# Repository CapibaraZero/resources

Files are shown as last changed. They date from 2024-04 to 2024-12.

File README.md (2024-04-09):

# CapibaraZero Resources

Here lives the resources needed for building a complete CapibaraZero

## Structure

- PCB/ Gerber and EasyEDA JSON files
- electrical_diagram/ Electrical diagram of CapibaraZero in PNG and EasyEDA JSON
- STL/ Box of capibaraZero

### Supported platforms

- CapibaraZero ESP32-S3-DevKitC-1
- CapibaraZero Arduino Nano ESP32

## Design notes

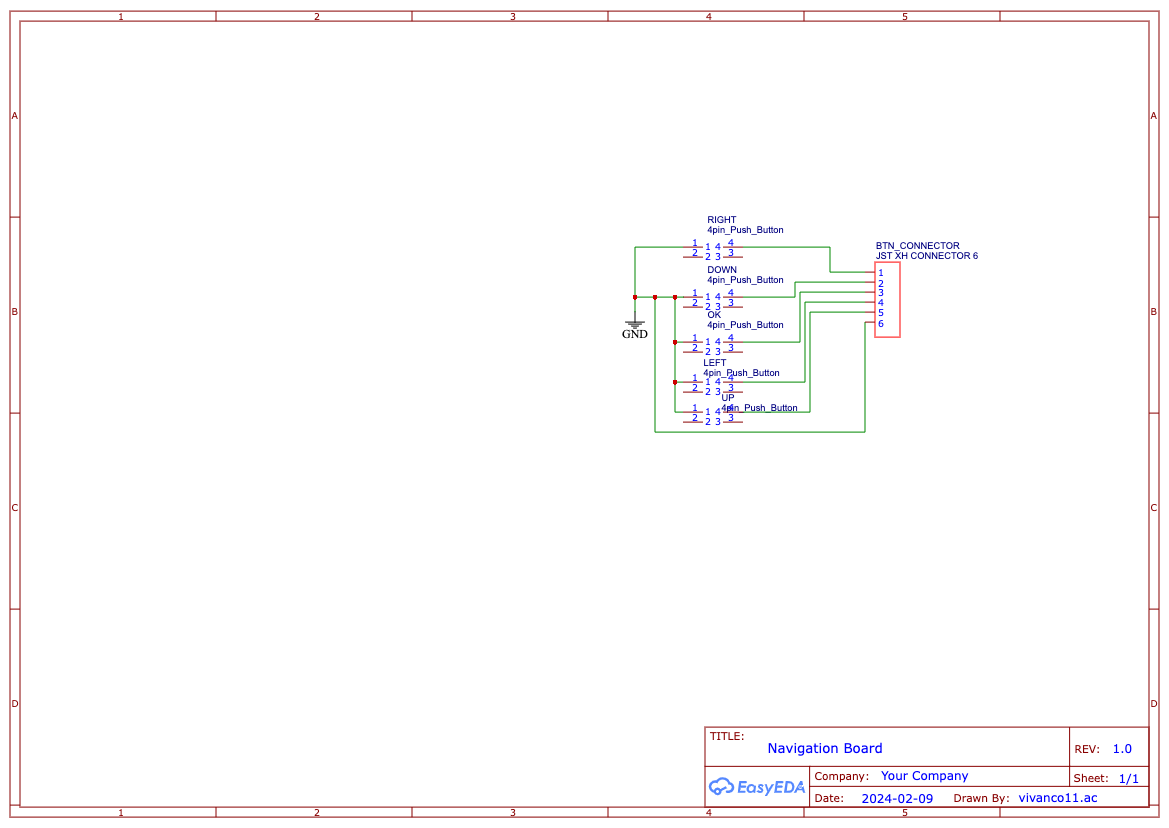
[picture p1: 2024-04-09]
electrical_diagram/ESP32-S3-DEVKITC-1/Schematic_CapibaraZero_Navigation_Board_2024-04-09.png

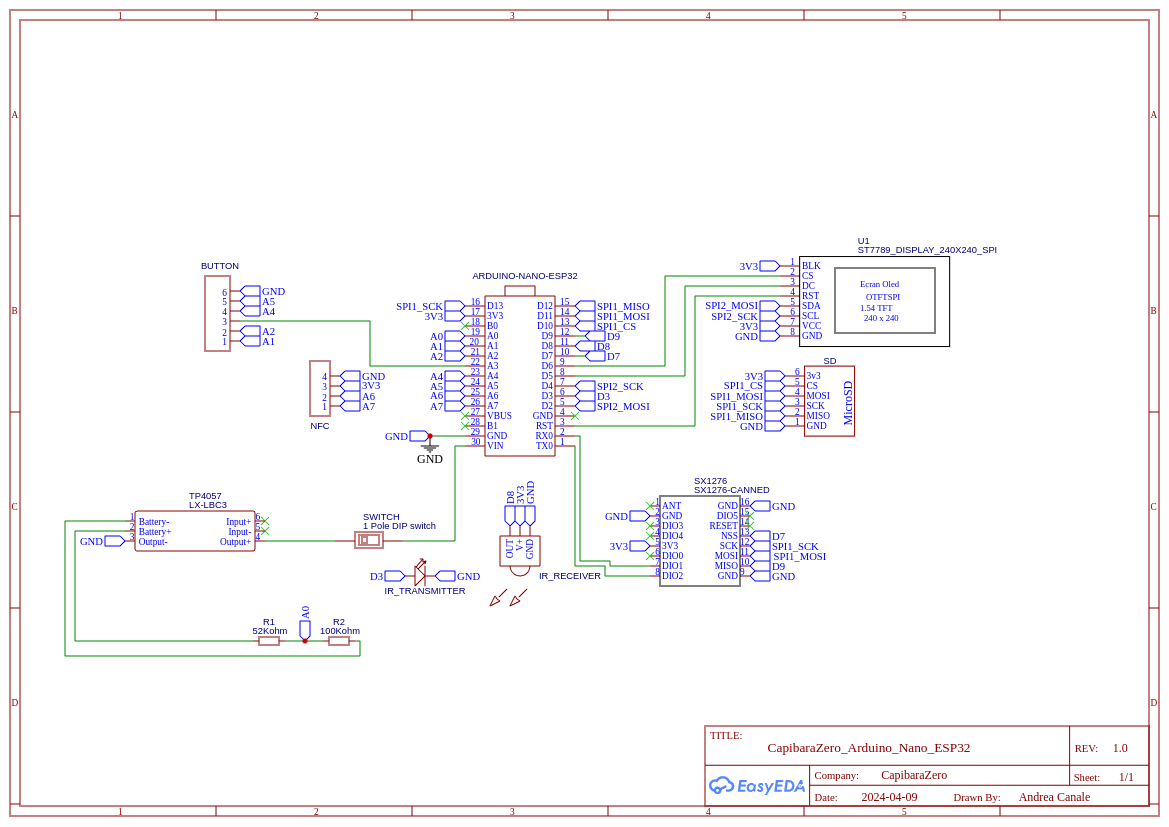
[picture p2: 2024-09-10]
electrical_diagram/Arduino_Nano_ESP32/MainScheme.png

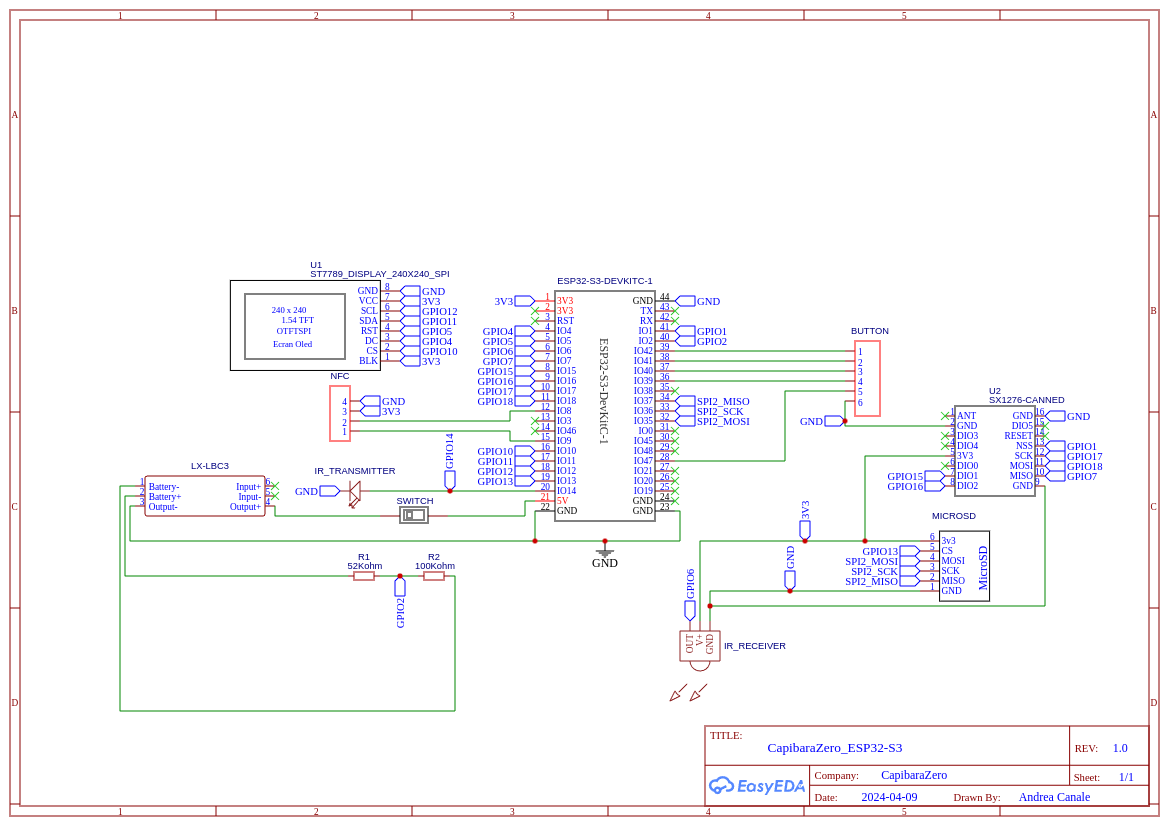
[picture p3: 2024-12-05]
electrical_diagram/ESP32-S3-DEVKITC-1/MainScheme.png

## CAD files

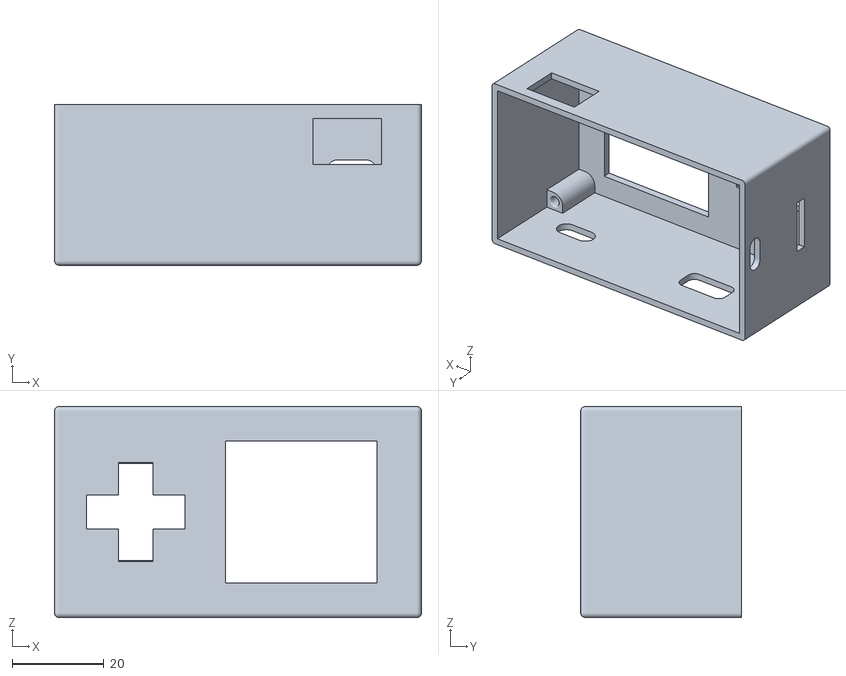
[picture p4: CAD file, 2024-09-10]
STL/arduino_nano_esp32/case_capibaraZerov1.STL
80.0 x 35.0 x 46.0

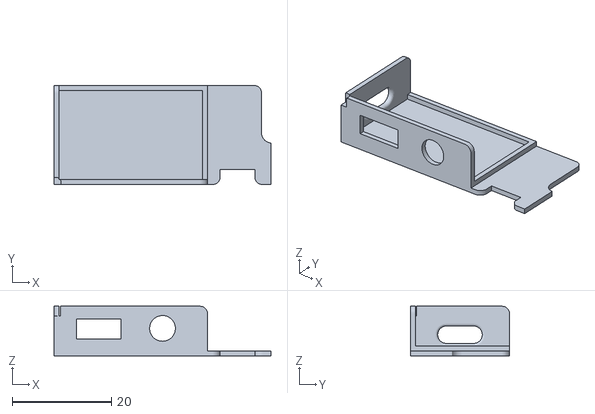
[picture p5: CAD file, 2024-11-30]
STL/ESP32-S3-DEVKITC-1/Charger_Rack.stl
43.8 x 20.0 x 10.0

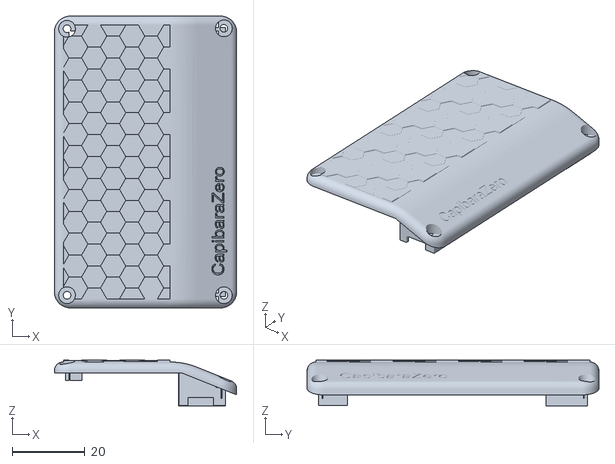
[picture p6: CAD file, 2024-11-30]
STL/ESP32-S3-DEVKITC-1/Top.stl
50.0 x 80.0 x 12.5

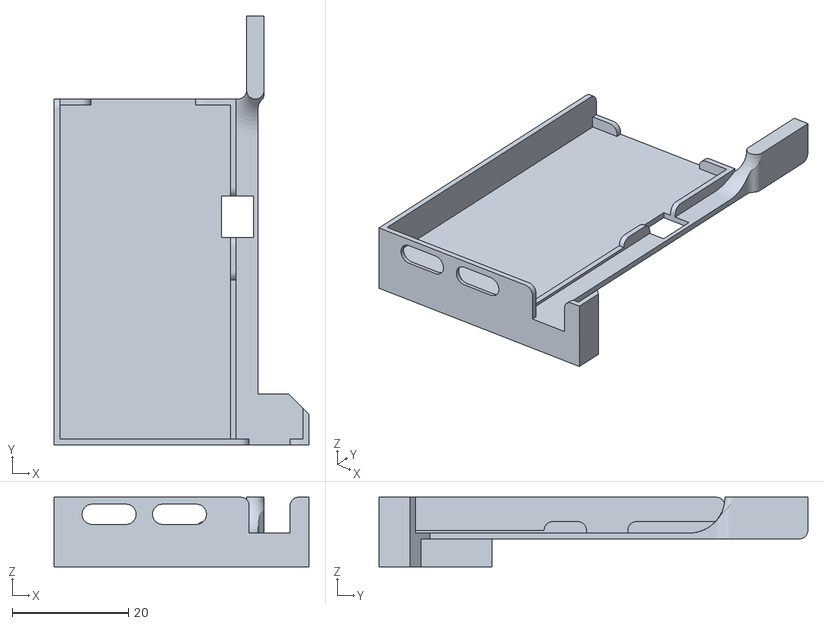
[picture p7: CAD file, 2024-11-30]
STL/ESP32-S3-DEVKITC-1/ESP32S3_Rack.stl
43.8 x 73.8 x 12.0

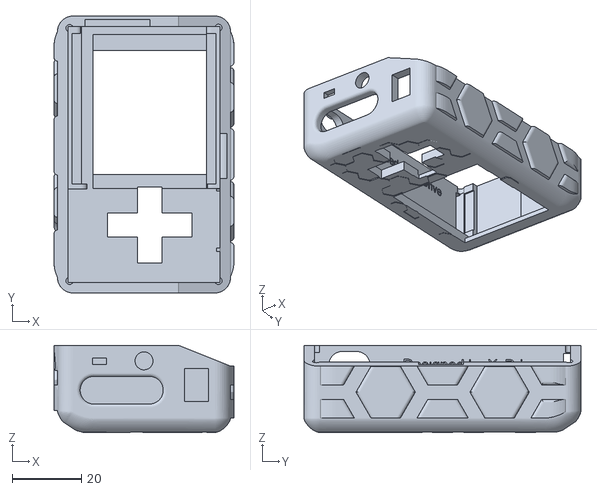
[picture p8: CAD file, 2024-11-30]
STL/ESP32-S3-DEVKITC-1/CapibaraZero_Case.stl
52.0 x 80.0 x 25.2

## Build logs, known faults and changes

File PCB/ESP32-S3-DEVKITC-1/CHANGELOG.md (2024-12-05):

# 1.1.2(2024-12-05
- Wire SX1276 in a separated SPI bus

# 1.1.1(2024-07-21)

- Larger SX1276 pad
- Put SX1276 MISO on separated line than SD card to avoid conflict(GPIO 7)
- Put IR receiver on GPIO 6
- Put display in higher position to fit better in box

# 1.1.0(2024-07-02)

- Added SX1276
- Put display on back
- Improve TP4057 footprint
- Add mounting holes for case
- Lighten ESP32-S3 pins
- Enlarge button connector pins
- Put USB at the end of PCB

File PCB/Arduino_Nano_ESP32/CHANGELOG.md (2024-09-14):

# 1.1.2(2024-09-14)

- Put DIO0 and DIO1 in D0 and D1 to avoid issues with IR
- Add more label on the footprint
- Update navigation board pin to be easier to solder

# 1.1.1(2024-07-21)

- Display RST to Arduino RST
- Larger SX1276 pad
- Put SX1276 MISO on separated line than SD card to avoid conflict(D9)
- Put display in higher position to fit better in box
 
# 1.1.0(2024-07-02)

- Added SX1276
- Put battery monitor on A0
- Put IR on D3/D8
- Put display on back
- Swap SDA and SCL on display
- Improve TP4057 footprint
- Add mounting holes for case

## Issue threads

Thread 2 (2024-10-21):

SMD Version of ESP32 PCB

PandemiK911, 2024-10-21:
Hello,
I've started adapting your schematic to create an SMD (Surface Mount Device) version using Kicad 8. Here's a quick preview of the work in progress. It's still missing many traces and connectors for the SX1276, microSD, and display.

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

I used the same dimensions as the original board so that the new board can fit in the existing enclosure.

I couldn't find a microSD connector with through-hole headers. Can you please provide information on the placement of this connector on the board ?

Before going further, I'd like to know if this project is useful for you or if I'm wasting my time.
Of course, all Kicad files would be released as the same license as the original project.

andreock, 2024-10-21:
This is a great idea, we can avoid process of soldering with a SMD PCBA. I think you can also make the PCB smaller than original so we can save some space and make capibaraZero more similar to FlipperZero case then I will adapt the case for your PCB. Thank you, your contribution it's really appreciated

PandemiK911, 2024-10-21:
Glad to hear that !
I have a few days of vacation, I'll do my best to obtain a first version so you can give your feedback on it.

I'll be hard to remove completely through-hole components, specifically the display.
But, for example, we can get rid of the 5V rail : all devices only use 3.3V so it's useless to boost battery to 5V to inject into devkit regulator. That should greatly improve battery autonomy.

andreock, 2024-11-30:
Hi, is there any progress?

Closed 2025-02-01.

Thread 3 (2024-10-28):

PCB suggestion

Kalrkloss, 2024-10-28:
I'm moving this here, because it belongs to the hardware folder.
The discussion so far:

Me:
Or make our own.
Maybe we can start by collecting the requirements, like display type, size, controls, battery, included communication modules, expansion bus, etc.
BTW., the ESP32 is pretty flexible when it comes to IO functions, it can route pretty much every special function to every GPIO.

I'll start:

    Compact housing resembling a somewhat bigger USB stick
    Integrated (LIION) battery and charging chircuit
    Display: (I would prefer a smaller, transflective LCD, because it's visible in full sunlight so options:)
    a) Big touch TFT
    b) small (non touch) TFT
    c) small transflective (monochrome) LCD
    Rotary encoder + maybe additional buttons
    Expansion port with 3.3V, GND and as many GPIOs as possible, 2.54 or 1.27 pitch (2.54 is better for DIY, but'll get huge). Maybe compatible to Flipper Zero?
    Micro SD card
    Integrated communication:
        WiFi, Bluetooth (already in the ESP32)
        LoRa 433MHz and/or 868/915MHz
        CC1101 433MHz and/or 868/915MHz (LoRa modules can't do ASK)
        NFC 13,56 MHz + antenna
        rfID 125kHz + antenna
        Infrared receiver/transmitter. Transmitter should be high power for TV-B-Gone
        USB A host port
        I2S codec with microphone and loudspeaker

Extension modules (should have I2C EEPROM for automatic identification):

    CAN bus (ESP32 already has one, so only transceiver needed)
    wideband SDR transceiver
    VHF/UHF transceiver Module (e.g. DRA818V)
    USDR compatible HF transceiver
    simple I/Q shortwave SDR receiver
    SI4732 based all-band receiver
    additional LoRa/CC1101 for multiband and relay
    JTAG/SWD debugger

andreock:
This can be a really good idea to save space and to make board ready for usage without soldering anything. A board based on ESP32-S3 with:

    2 USB
    a ST7789 display(maybe 1.54")
    CC1101/SX1276(not both)
    SD card slot
    PN532(or even something better)
    RFID(maybe)
    IR
    Li-ion battery circuit
    5 push button like flipper

Can be a good starting point. I don't have much time to work on it but if anyone can help me, the result will be very interesting.

Me:
Why two USB? The ESP32-S3 has a native USB, which, by default, acts as a composite device consisting of a CDC serial port and a JTAG interface, for programming and debugging the chip.

So, even if you dedicate the serial port to host communication, you always have the JTAG left for debugging and programming.
Sure, some commercial boards have additionally a USB-to-serial chip, connected to the ESP's hardware serial port, but this isn't necessary at all, unless you reprogram the native USB to something else and still want to have an additional USB serial port.

Me (new):
I'd like to add another ESP32 module (C5 maybe) to handle the 6GHz and IEEE 802.15.4 stuff.

PandemiK911, 2024-10-28:
Perhaps could me merge with #2 ?
I started designing a SMD PCB.

What is done actually :
- a 2-sides PCB same size as the actual one. Integrated ESP32-S3 module and power circuit with USB (DATA -> ESP32 D+/D-)  + TP4057 + 3.3V buck regulator + on/off switch + battery connector (JST XH).
- footprints to solder actual TH SX1276 PCB (2x08), JST XH header for buttons and ST7789 display (1x08)
- IR 38 kHz receiver and sender

All components in BOM are available at LCSC so it won't be difficult to order them.

Right now, I haven't been able to find a TH microsd socket. I'll go for a SMD version but that implies to solder on both sides (harder with SMD stencils).
Still have to figure how I could integrate PN532 and CC1101 as they needs antennas and that's not easy to design properly.

I also haven't been able to find reference for a 240x240 1,54" SPI TFT display. If someone could point me to a page, I will try to integrate it of find a replacement part.
Waveshare does some nice e-ink displays like those :
- 1.54" 200x200 : https://www.lcsc.com/product-detail/E-ink-Display_Waveshare-1-54inch-e-Paper_C5374685.html
- 2.13" 250×122 : https://www.lcsc.com/product-detail/E-ink-Display_Waveshare-2-13inch-e-Paper_C18198401.html

About USB host : ESP32-S3, ESP32-C3 and ESP32-C6 seems to have USB OTG. Espressif's product range is pretty complex ;-)
So if we have enough GPIO, ESP32-C6-MINI-1 is a good candidate : Wifi6, BLE5.3, Thread/Zigbee, USB OTG ... This is my reference MCU for new designs.

My idea is really to start with something easy to build and debug errors with already known components. Most of the time, you can't expect design a PCB from scratch and having it perfect at the first attempt.

Some good ideas so far ! Does someone wants to work on any part of the PCB ? I'm using Kicad and schematics can be split in sheets that allows multiple contributors. I'll be more than happy to share the actual work (how ?).

andreock, 2024-10-29:
Yes it's a good idea to merge issues #2 #3 togheter. If you need footprint + reference, I can share the ones that I used for the PCB. Are you sure about ESP32-C6 supporting USB-OTG? https://esp32.com/viewtopic.php?t=32196 check also datasheet https://www.espressif.com/sites/default/files/documentation/esp32-c6_datasheet_en.pdf USB-OTG is not mentioned

PandemiK911, 2024-10-31:
My bad, you're right : ESP32-C3/C6 doesn't have USB-OTG. I was confused by the availability of CDC-ACM that can only be used as a serial port :

> [USB Serial/JTAG Controller Console](https://docs.espressif.com/projects/esp-idf/en/stable/esp32c6/api-guides/usb-serial-jtag-console.html)
The USB Serial/JTAG Controller is a fixed-function USB device that is implemented entirely in hardware, meaning that it cannot be reconfigured to perform any function other than a serial port and JTAG debugging functionality. This is in contrast to the USB OTG controllers in some ESP chips that can be configured to perform the function of multiple types of USB devices.

Do we need CapibaraZero to be able to emulate something else than serial port on USB (eg storage device class) ?

(don't forget I don't have an actual device in hands and have not been able to test functionalities).

andreock, 2024-10-31:
Storage MSC+HID will be available in the next release to make BadUSB compliant with Duckyscript 3.0, so the chip must support USB OTG to use BadUSB section.

andreock, 2024-12-22:
Hi, is there any progress?

Closed 2025-02-03.

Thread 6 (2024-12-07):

Deprecate PCB

andreock, 2024-12-07:
Until someone will contribute with a decent PCB design, deprecate current version in favor of stripboard/soldered design

Closed 2025-02-03.

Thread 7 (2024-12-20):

3D model is not correct for ESP32-S3-DEVKITC-1

mortal541, 2024-12-20:
Hi
Thank you very much for putting all of this together. I started building the ESP32-S3-DEVKITC-1 version, but after printing the case, I realized it’s significantly too small and out of dimensions. Could you please provide the .STEP files so I can make corrections and share the updated version with the community?

Thank you again, and wishing you a Happy New Year!

andreock, 2024-12-22:
Sorry for the late reply, the case is not intended to be used with the PCB @XyDrive is making a guide to build ESP32-S3 case without using PCB. **PCB will be deprecated in next release**

mortal541, 2024-12-22:
Hi
No worries. If you can share the step file I can update the case to fit the current pcb.

Thank you very much for this project

XyDrive, 2024-12-22:
Here you are :3

[Capibarazero case (v27~recovered).zip](https://github.com/user-attachments/files/18223088/Capibarazero.case.v27.recovered.zip)

mortal541, 2024-12-23:
Thank you. I'll start working on right away

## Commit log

2024-07-01 Update to 1.1.0
    [Drill_NPTH_Through.DRL, Drill_PTH_Through.DRL, Drill_PTH_Through_Via.DRL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]
2024-07-02 Ignore How-to-order-PCB.txt
2024-09-10 Update to 1.1.2
    [Drill_NPTH_Through.DRL, Drill_PTH_Through.DRL, Drill_PTH_Through_Via.DRL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]
2024-09-10 Add Arduino Nano ESP32 case
    [case_capibaraZerov1.STL]
2024-09-10 Add more label on PCB
    [Drill_NPTH_Through.DRL, Drill_PTH_Through.DRL, Drill_PTH_Through_Via.DRL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]
2024-09-14 Update PCBs
    [Drill_NPTH_Through.DRL, Drill_PTH_Through.DRL, Drill_PTH_Through_Via.DRL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]
2024-10-04 Shortening Marantz's amplifier button name
2024-11-29 Fix mkfs make_sdcard.sh
    fix hardcoded device name
2024-11-30 Add ESP32S3 STL
    [CapibaraZero_Case.stl, Charger_Rack.stl, ESP32S3_Rack.stl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]
2024-12-05 Update ESP32-S3 PCB to 1.1.2
    [Drill_NPTH_Through.DRL, Drill_PTH_Through.DRL, Drill_PTH_Through_Via.DRL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]
2025-02-24 Add initial case for Raspberry PI Zero 2W
